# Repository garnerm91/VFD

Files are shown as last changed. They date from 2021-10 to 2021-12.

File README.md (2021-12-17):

# Futaba VFD Controlled by Arduino
This is an Arduino-based project using Futaba vacuum fluorescent displays.  In this project, I used Futaba part number BL-141G (GM part number 09367240), a MIC5891 to drive the screen, and an Arduino. This Vacuum Fluorescent Display is off of a 03-05 GM Truck Instrument Clusters and on Trailblazers. The Arduino code is a rough sketch to get started with but functions well. 

My PCB are from [JLCPCB](https://jlcpcb.com/IAT), new users have $30 coupons [here](https://jlcpcb.com/IAT)

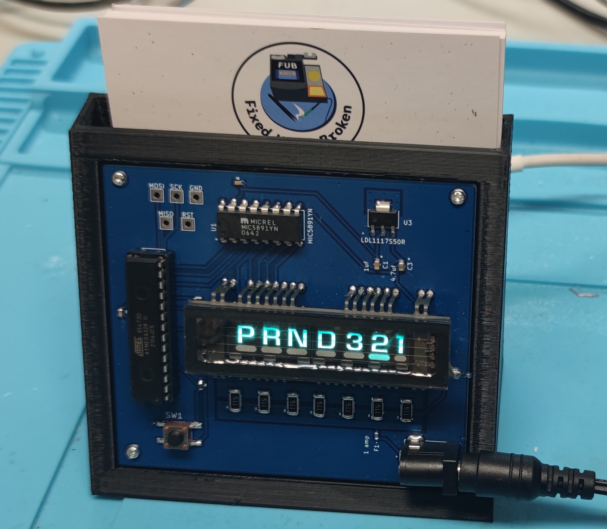
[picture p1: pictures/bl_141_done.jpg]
BL-141G Completed


Design work was done in Kicad

Video 1: https://youtu.be/h8Us6riXLtg
Video 2: https://youtu.be/K12hVGqjaFM

# Goal
The goal of this project to make footprints and working examples of existing VFDs that are "out in the wild". Unfortunately Futaba would not providde datasheets. This project guide contains the files necessary to help you step by step produce your own PCB using the screens

# Screens
Right now the only screen supported is Futaba BL-141G and BL-186GIN in the 07-14 folder. I do have access to more of them and will add support over time.

BL-141G Front
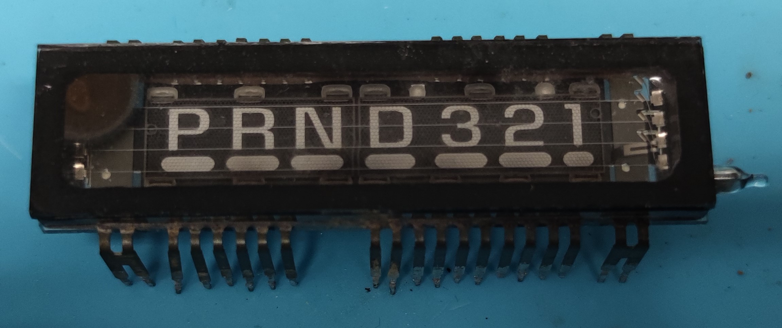
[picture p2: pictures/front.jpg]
BL-141G front


BL-141G Back
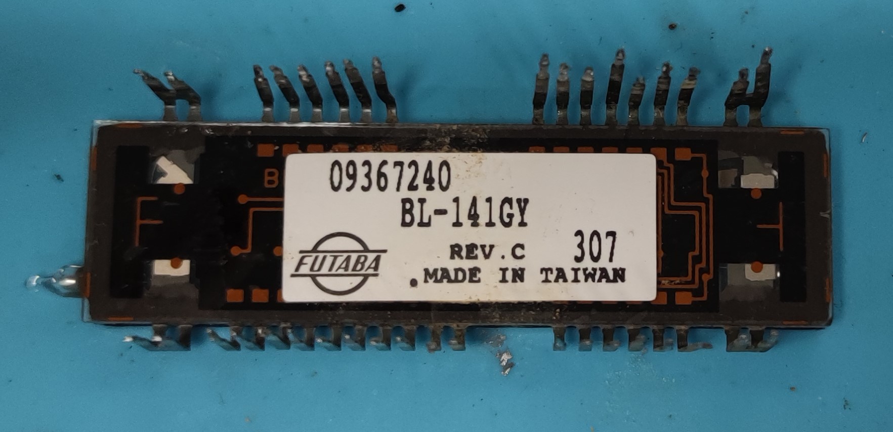
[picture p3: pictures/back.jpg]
BL-141G back


# Kicad Files
 bl-141g.lib is the symbol and BL-141G.kicad_mod is the footprint.

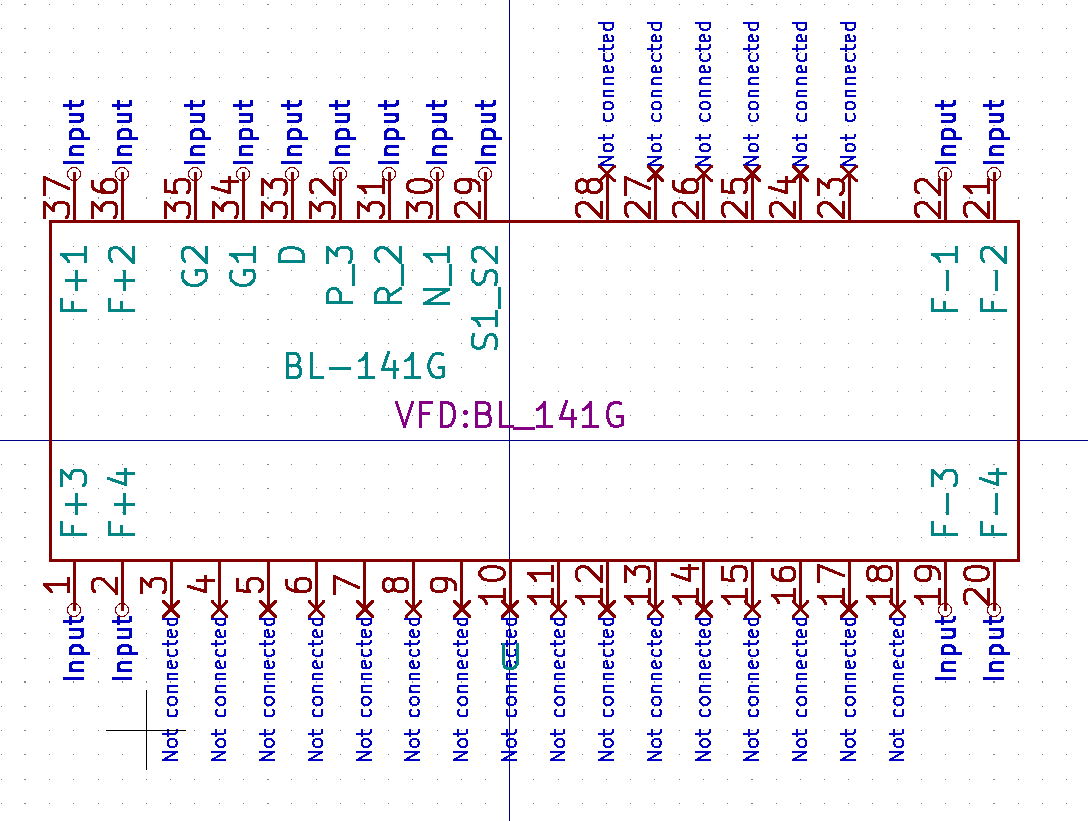
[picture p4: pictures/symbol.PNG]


# Housing & 3D Printing
The housing is open air to show off the PCB. It also helps with cooling the resistors for the VFD filiment. I will try to keep the board footprint the same in future projects with VFDs so that way this same housing can be used on it. I 3d printed it 20% infill and supports with PETG. [Housing](housing.stl) The housing itself is designed to hold business cards so that way it is a functional work of desk art.

# Assembly & Programming
This smallest compents are 0603 so this is achiveable at home with any decent soldering iron. The XTAL is going to need hot air or hotplate. If you are salvaging the screen yourself off a GM Truck CLuster you can also salvage the 510 ohm resistors off the board at the same time if building the BL-141G. I personally prefer to use solderpaste and hot air for all the SMT components myself.

As for programming you can use an arduino as ISP using the header provided above the Microcontroller. I personally prefer to use a TL866 to program them. Attached Below is a screenshot of the Fuse setting for the ATmega328 
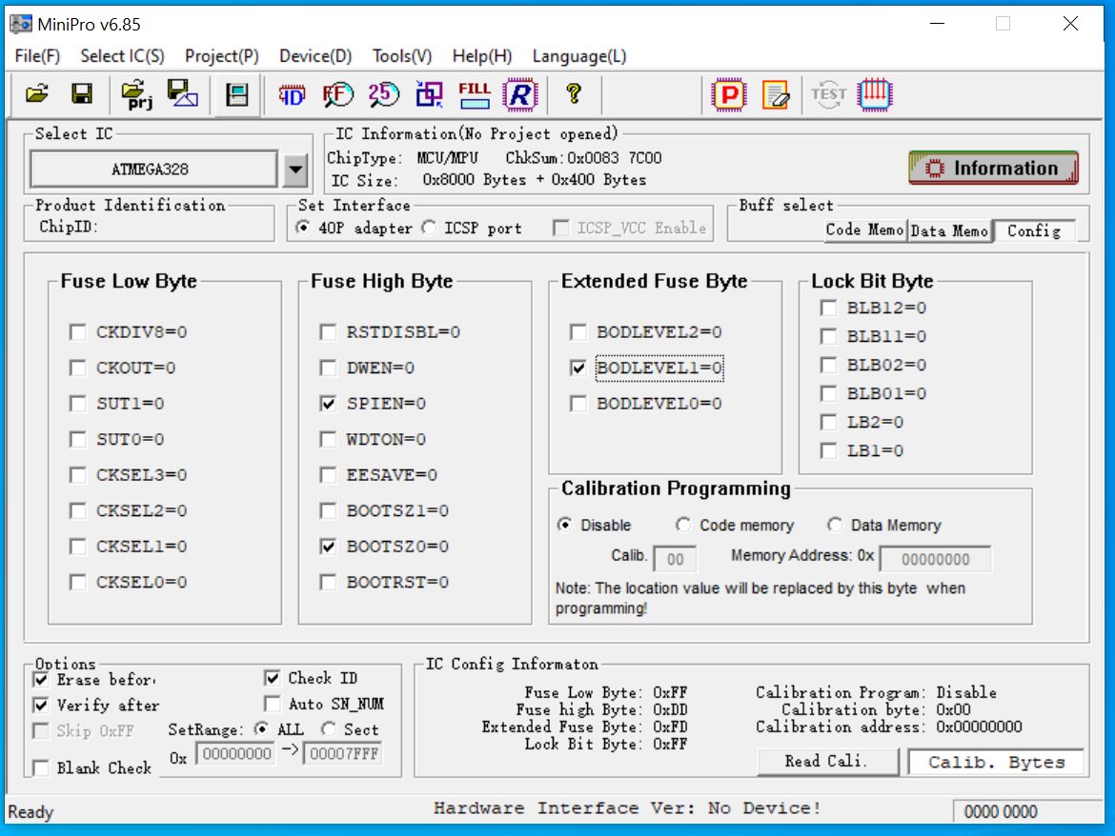
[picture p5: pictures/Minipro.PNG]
Minipro


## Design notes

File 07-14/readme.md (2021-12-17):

This is for 07-14 GM truck VFD. For the housing its the same as the 03-05 one in the master folder.

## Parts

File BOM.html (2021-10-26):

Ref | Qnty | Value | Part | Datasheet | Description | Vendor
C1 | 1 | 1UF | CL21F105ZAFNNNF:CL21F105ZAFNNNF
C2, C4, C5 | 3 | .01UF | 0603YC104MAT4A:0603YC104MAT4A
C3 | 1 | 4.7UF | CL21F105ZAFNNNF:CL21F105ZAFNNNF
F1 | 1 | MFU0603FF01000P500 | MFU0603FF01000P500:MFU0603FF01000P500
J1 | 1 | CON-SOCJ-2155 | CON-SOCJ-2155:CON-SOCJ-2155
R1, R2, R3, R4, R5, R6, R7 | 7 | 510ohm 2010 case | CRGP2010F150R:CRGP2010F150R
R8 | 1 | ESR03EZPJ103 | ESR03EZPJ103:ESR03EZPJ103
SW1 | 1 | FSM4JSMA | FSM4JSMA:FSM4JSMA
U1 | 1 | MIC5891YN | MIC5891YN:MIC5891YN
U2 | 1 | BL-141G | VFDs:BL-141G |  | Futuba VFD
U3 | 1 | LDL1117S50R | ldl1117s50r:LDL1117S50R
U4 | 1 | ATmega328-PU | MCU_Microchip_ATmega:ATmega328-PU | http://ww1.microchip.com/downloads/en/DeviceDoc/ATmega328_P%20AVR%20MCU%20with%20picoPower%20Technology%20Data%20Sheet%2040001984A.pdf | 20MHz, 32kB Flash, 2kB SRAM, 1kB EEPROM, DIP-28
Y1 | 1 | CSTNE16M0V530000R0 | CSTNE16M0V530000R0:CSTNE16M0V530000R0

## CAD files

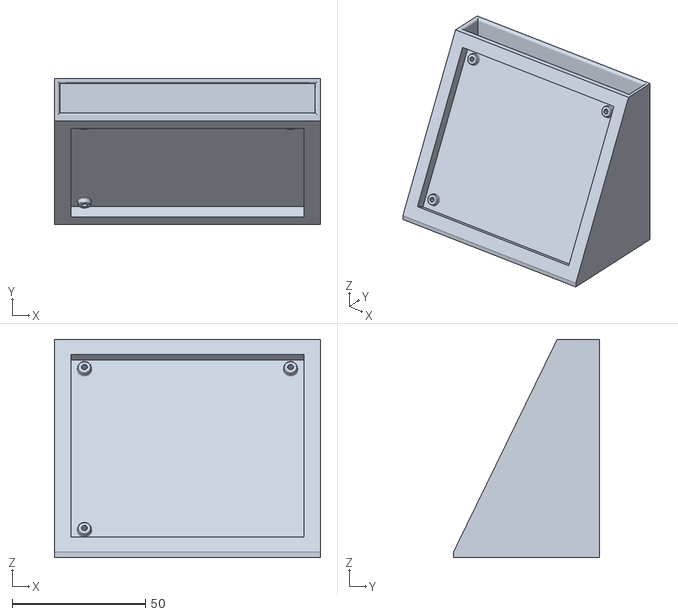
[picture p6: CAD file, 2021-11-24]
housing.stl
100.0 x 55.0 x 82.0

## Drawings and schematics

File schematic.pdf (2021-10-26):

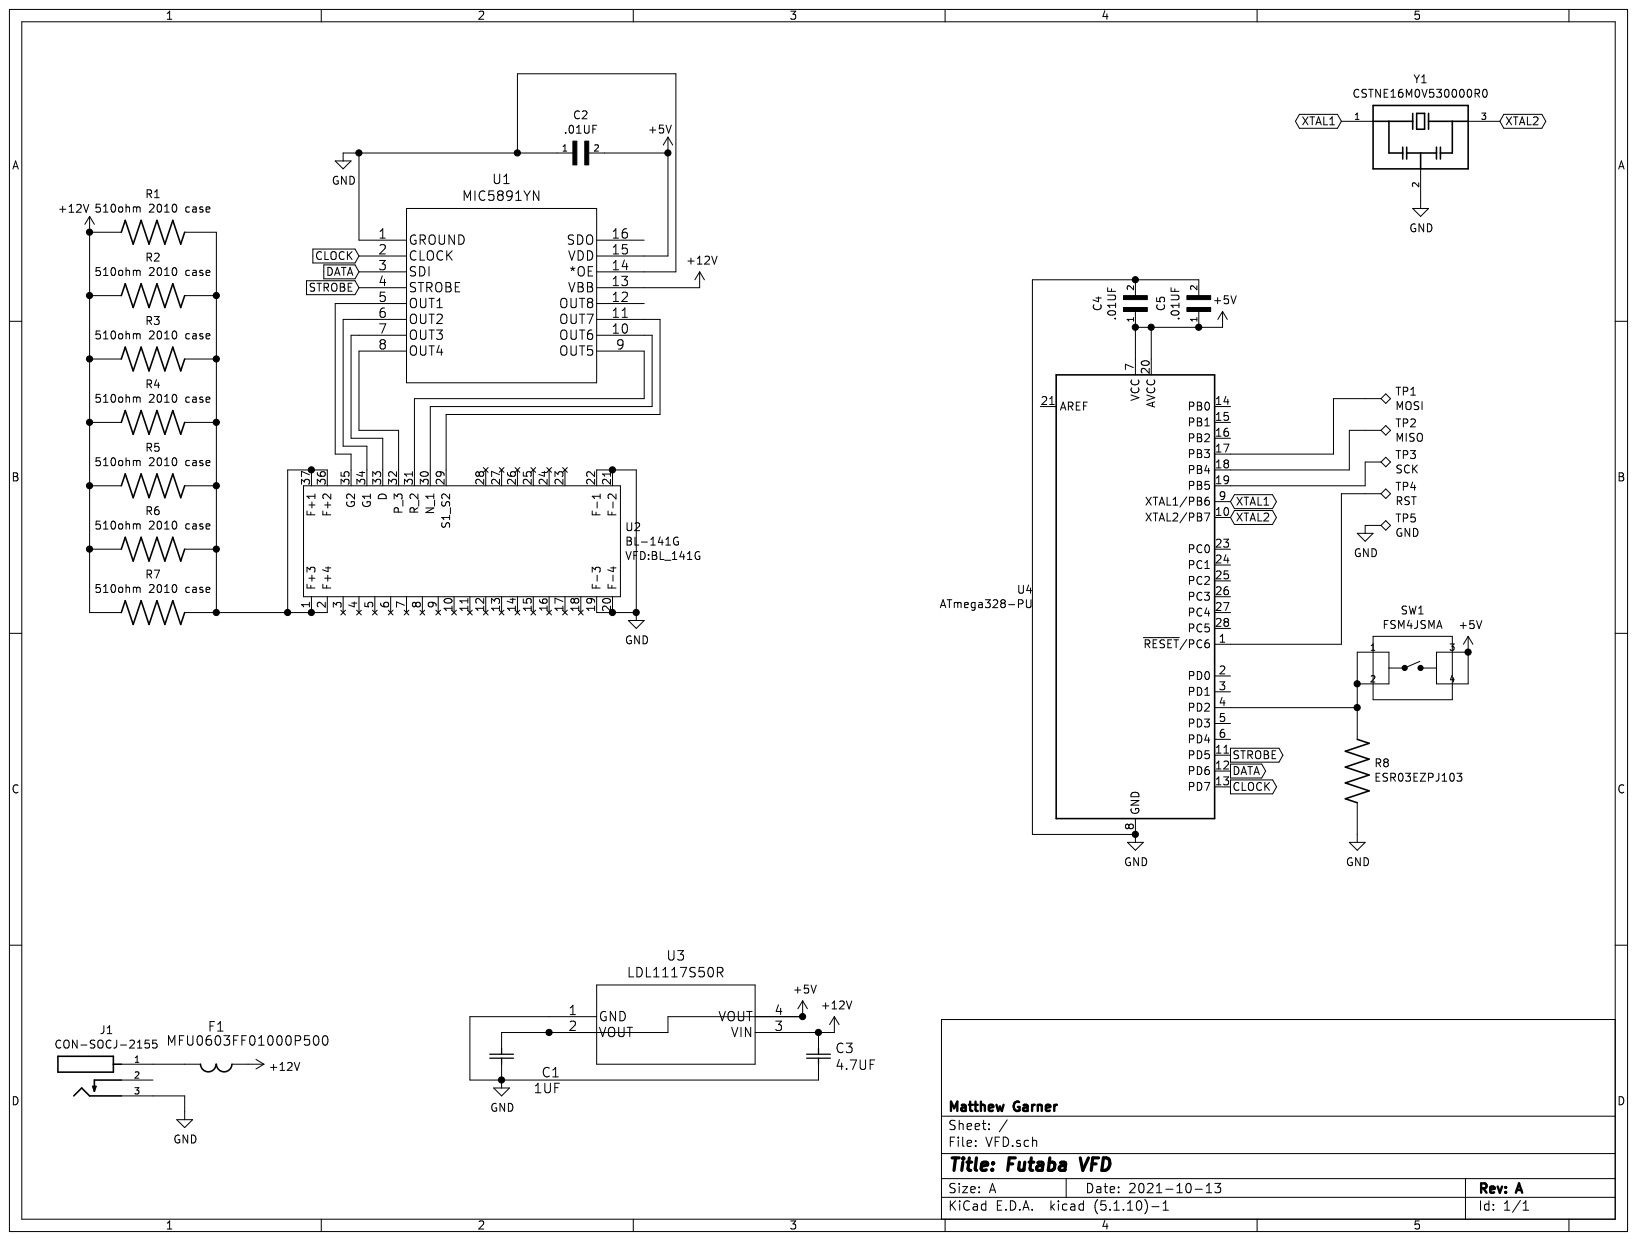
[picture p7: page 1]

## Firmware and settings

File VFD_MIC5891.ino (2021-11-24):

/*
 hex table for prndl
 0xc2 = prnd123 on (both grids)
 0x90 = (P underlined)
 0x88 = (R underlined)
 0x84 = (n underlined)
 0X60 = (D underlined)
 0x50 = (1
 
 
 */

#define MIC_S        5
#define MIC_C        7
#define MIC_D        6
#define BTN        2



void setup() {
 pinMode(MIC_S, OUTPUT);
 pinMode(MIC_C, OUTPUT);
 pinMode(MIC_D, OUTPUT);
 pinMode(BTN, INPUT);

}

void screen(int value){
  digitalWrite(MIC_S, LOW);
  for (int i = 0; i <= 7; i++) {
   digitalWrite(MIC_D, bitRead(value, i));
   digitalWrite(MIC_C, HIGH);
   digitalWrite(MIC_C, LOW);
  }
  digitalWrite(MIC_S, HIGH);     
}

void pollbttn(){
 if (digitalRead(BTN) == HIGH){
    screen(0xC2);
    delay(650);
    }
 }
   
void loop() {
  long starttime = millis();
  long endtime = starttime;
  while ((endtime - starttime) <=200) 
    {
    screen(0xC2);
    delay(7);
    screen(0x90);
    delay(7);
     pollbttn();
    endtime = millis();
   }
  starttime = millis();
  endtime = starttime;
    while ((endtime - starttime) <=200) 
    {
    screen(0xC2);
    delay(7);
    screen(0x88);
    delay(7);
     pollbttn();
    endtime = millis();
  }
 starttime = millis();
  endtime = starttime;
    while ((endtime - starttime) <=200) 
    {
    screen(0xC2);
    delay(7);
    screen(0x84);
    delay(7);
     pollbttn();
    endtime = millis();
  }
 starttime = millis();
  endtime = starttime;
    while ((endtime - starttime) <=200) 
    {
    screen(0xC2);
    delay(7);
    screen(0x60);
    delay(7);
     pollbttn();
    endtime = millis();
  }
 starttime = millis();
  endtime = starttime;
    while ((endtime - starttime) <=200) 
    {
    screen(0xC2);
    delay(7);
    screen(0x50);
    delay(7);
     pollbttn();
    endtime = millis();
  }
 starttime = millis();
  endtime = starttime;
    while ((endtime - starttime) <=200) 
    {
    screen(0xC2);
    delay(7);
    screen(0x48);
    delay(7);
     pollbttn();
    endtime = millis();
  }
 starttime = millis();
  endtime = starttime;
    while ((endtime - starttime) <=200) 
    {
    screen(0xC2);
    delay(7);
    screen(0x44);
    delay(7);
     pollbttn();
    endtime = millis();
  }
 starttime = millis();
  endtime = starttime;
 while ((endtime - starttime) <=200) 
    {
    screen(0xC2);
    delay(7);
    screen(0x48);
    delay(7);
     pollbttn();
    endtime = millis();
   }
  starttime = millis();
  endtime = starttime;
    while ((endtime - starttime) <=200) 
    {
    screen(0xC2);
    delay(7);
    screen(0x50);
    delay(7);
     pollbttn();
    endtime = millis();
  }
 starttime = millis();
  endtime = starttime;
    while ((endtime - starttime) <=200) 
    {
    screen(0xC2);
    delay(7);
    screen(0x60);
    delay(7);
     pollbttn();
    endtime = millis();
  }
 starttime = millis();
  endtime = starttime;
    while ((endtime - starttime) <=200) 
    {
    screen(0xC2);
    delay(7);
    screen(0x84);
    delay(7);
     pollbttn();
    endtime = millis();
  }
 starttime = millis();
  endtime = starttime;
    while ((endtime - starttime) <=200) 
    {
    screen(0xC2);
    delay(7);
    screen(0x88);
    delay(7);
     pollbttn();
    endtime = millis();
  }
}
